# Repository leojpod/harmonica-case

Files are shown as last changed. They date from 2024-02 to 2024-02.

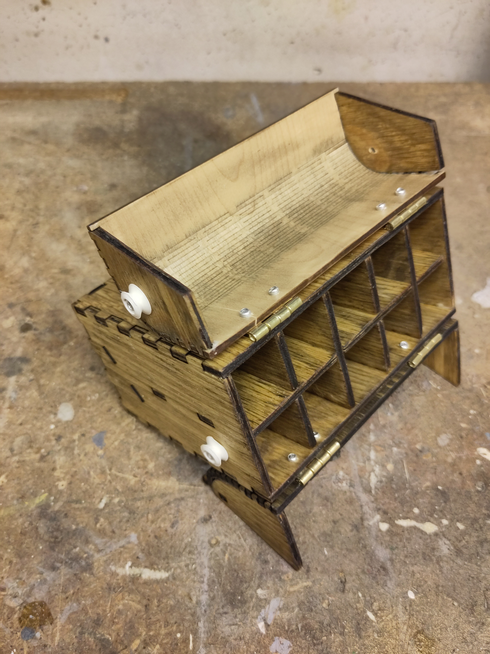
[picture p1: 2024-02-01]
pictures/IMG_20221201_205347.jpg

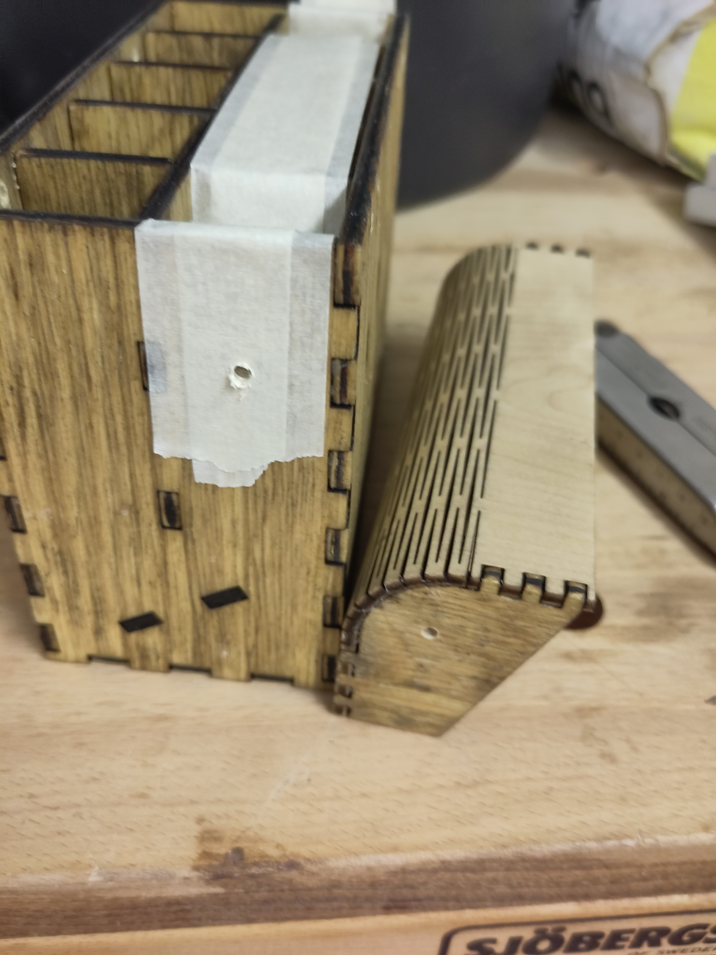
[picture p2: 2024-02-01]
pictures/IMG_20221201_195854.jpg

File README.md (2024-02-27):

# Harmonica carry-case (and show off stand)

## TL;DR

The idea is to create a case that can carry safely about 10 diatonic harmonicas.
The case should also open in a way that would allow to easily locate and pick up the desired harmonica.

## The story behind this

I used to put my harmonicas on my hand made stand-up desk, but I start to have too many to line up like in this picture.



After a few drawing on paper, I thought "why not make something that could hold my harmonicas but also display them".
Few more paper draft later, I started to play with FreeCAD, but I was quite unhappy with it eventually, and I like the ability to "code" my model and to version it.

For specific information about each file, check their "headers".

## How to assemble it?

First, set up the variables in `dimensions.scad`, and make sure they match your harmonicas (or whatever you want to store) and the base material you wish to use.

Then check the `main.scad` file with OpenSCAD, and make sure it looks OK.
Don't hesitate to comment out part of the `BoxOutset` to see inside more easily.

The whole thing is meant to be assembled from laser cut parts.

### 3 by 5 box

#### laser-cut pieces

All the pieces are cut on some 4 mm thick laminated wood.

- For the inset:
  - [ ] 1 horizontal plank
  - [ ] 1 slant plank
  - [ ] 2 even vertical separators
  - [ ] 2 odd vertical separators
- For the outset:
  - [ ] 1 bottom
  - [ ] 2 long side "a"
  - [ ] 2 long side "b"
  - [ ] 2 short side "a"
  - [ ] 2 short side "b"
- For the lid-lock:
  - [ ] 1 example support (optional to check the lock works)
  - [ ] 10 holders
  - [ ] 4 handles
  - [ ] 2 long slider base
  - [ ] 2 short slider base
- For the lid:
  - [ ] the "stand lid part"
    - [ ] 2 stand side
    - [ ] 1 "stand" cover
    - [ ] 1 stabiliser with overhead
  - [ ] the "other lid part"
    - [ ] 2 "other" side
    - [ ] 2 stabilisers without overhead
    - [ ] 1 "other" cover

### Other pieces & material

- the lid lock
  - **_TODO find one and explain it here_**
- the lid hinge joins
  - **_TODO Same_**
- the carry strings
  - **_TODO Same_**

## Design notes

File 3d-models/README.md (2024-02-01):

# 3d Models

Quick summary of the files and what they are used for:

- `dimansions.scad`: regroups different parameters that control the whole thing, mainly, how thick is the material we're working with, how big should be the holds for the harmonicas, how many holds should there be, etc.
- `box-inset.scad`: modelises the horizontal and vertical separators that go inside the box.
- `box-outset.scad`: modelises the outside of the box, this will hold the inset in place and the lid parts are going to attach to it.
- `lid.scad`: contains the 2 parts that are used for the lid.
- `string-lock.scad`: modelises the small things on the side that are used to hold the lid shut.
- `pop-rivet.scad`: was supposed to be used to seal the lid's hinges and the locks on the sides, but in the end I opted for real rivets.

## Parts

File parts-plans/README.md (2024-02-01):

# Part plans

Having a 3D model is fine but that does not give you a part to print/laser cut. So here is where this comes into play.

Depending on your setup, you might want to tweak this files a bit to export only one piece to SVG or some other format at a time.

I will try to find a better way to deal with this.
One idea for that:
https://3dprinting.stackexchange.com/questions/14900/export-stl-from-openscad-command-line-calling-module-within-script

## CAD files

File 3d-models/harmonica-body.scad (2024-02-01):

harmonicaHeight = 30;
harmonicaLength = 105;
harmonicaThickness = 20;

module harmonicaBody() {
    cube([harmonicaLength, harmonicaThickness, harmonicaHeight]);
}

rotate([0,90,0])
  translate([-harmonicaLength,0,0])
  harmonicaBody();

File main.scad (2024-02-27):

// Box body

/*   top
 *   ____
 *  /    \ <- lid
 *  |    |
 *  |    | <- short sides: left & right
 *  |____| <- long sides: front & back
 *   ^ bottom
 *
 *
 *   base: left, right, front, back & bottom (i.e. all but lid)
 */


/*
 * DIMENSIONS
 *
 * Harmonica:
 *  - roughly: 105 x 25 x 30
 *
 * harmonica stored along the X axis
 */
include <./3d-models/dimensions.scad>

use <./3d-models/harmonica-body.scad>

use <./3d-models/box-inset.scad>
use <./3d-models/box-outset.scad>
use <./3d-models/lid.scad>
use <./3d-models/lid-lock.scad>

rotate([0, -($boxTiltingAngle), 0]) {
  translate([$materialThickness,2*$materialThickness,2*$materialThickness]) {
    boxInset();
    // harmonicas as example
    color("white") {
      translate([(2 * $heightGap + $materialThickness) / tan(90-$slantAngle) + $materialThickness, 0, 0])
      for (i=[0:($horizontalPlacements - 1)]) {
        translate([0, i * ($thickGap + $materialThickness), 0])
          harmonicaBody();
      }
      translate([$heightGap/(tan(90-$slantAngle)) + $materialThickness + 2, 0, $heightGap + $materialThickness])
      for (i=[0:($horizontalPlacements - 1)]) {
        translate([0, i * ($thickGap + $materialThickness), 0])
          harmonicaBody();
      }
    }
  }

  boxOutset(extraSpace = 0);
  translate([$boxHeight, 0, 0])
  lid();
  translate([$boxHeight, 0, 0])
    rotate([0, 180, 0])
    standLid();
  translate([$boxHeight, 0, $boxDepth])
    rotate([0, 180, 0])
    translate([0, $boxWidth, 0])
    rotate([180, 0, 0])
    otherLid();

  translate([$boxHeight + $lidHeight*.80, $boxWidth, $boxDepth - 1.5*$lidRadius])
    mirror([0,1,])
    rotate([90, 180, 0])
    slideLock();
  translate([$boxHeight + $lidHeight*.80, 0, $boxDepth - 1.5*$lidRadius])
    rotate([90, 180, 0])
    slideLock();
}

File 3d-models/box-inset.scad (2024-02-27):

include <./dimensions.scad>
use <./harmonica-body.scad>

margin = 5;

insideWidth = $boxWidth - 4* $materialThickness;


function offsetCalculator(level) = 
  $insetMargin + $materialThickness + ($verticalPlacements - level) *($heightGap + $materialThickness) / tan (90-$slantAngle) + 2;


module insideSlant() {
  // inside-slant offset ->
  slantHeight = ($heightGap + ( $heightGap + $materialThickness) * ($verticalPlacements -1)) / sin(90 - $slantAngle) - $materialThickness;
  union() {
    cube([$materialThickness, insideWidth, slantHeight]);
    translate([0, - $materialThickness, (slantHeight / 3) - 5])
    cube([$materialThickness, insideWidth + 2 * $materialThickness, 10]);
    translate([0, - $materialThickness, 2 * (slantHeight / 3) - 5])
    cube([$materialThickness, insideWidth + 2 * $materialThickness, 10]);
  }
}


module horizontalPlank(height, level = 1) {
  echo("horizontalPlank -> ", level);
  offset = offsetCalculator(level);
  offsetted_height = height - offset;
  translate([offset, 0, 0])
  difference () {
    union() {
      //base
      cube([offsetted_height, insideWidth, $materialThickness]);
      // first set of wings
      translate([20, - $materialThickness, 0])
        cube([10, insideWidth + 2 * $materialThickness, $materialThickness]);
      // second set of wings
      translate([offsetted_height - 30, - $materialThickness, 0])
        cube([10, insideWidth + 2 * $materialThickness, $materialThickness]);
    }
    // notches
    for(i=[0:($horizontalPlacements - 2)]) {
      horizontalShift = (i + 1) * $thickGap + (i *  $materialThickness);
      if (i % 2 != 0){
        translate([offsetted_height / 2, horizontalShift, - margin ])
        cube([offsetted_height / 2 + margin, $materialThickness, 2*margin +  $materialThickness]);
      } else {
        translate([- margin, horizontalShift, - margin])
        cube([offsetted_height / 2 + margin, $materialThickness, 2*margin + $materialThickness]);
      }
    }
  }
}

module verticalSeparator(height, is_even = true) {
  offset = offsetCalculator(1);
  offsetted_height = height - offset;
  separator_width = $heightGap + ($verticalPlacements - 1) * ($materialThickness + $heightGap);

  base = 4 + margin + $insetMargin;
  bottomOffset = base + (separator_width + 2 * margin) / tan(90-$slantAngle);

  // wedge cutout
  wedgePoints = [
    [0, 0, separator_width + 2 * margin], // 0
    [base, 0, separator_width + 2 * margin], // 1
    [bottomOffset, 0, 0], // 2
    [0, 0, 0], // 3
    [0, $materialThickness + 2 * margin, separator_width + 2 * margin], // 4
    [base, $materialThickness + 2 * margin, separator_width + 2 * margin], // 5
    [bottomOffset, $materialThickness + 2 * margin, 0], // 6
    [0, $materialThickness + 2 * margin, 0] // 7
  ];
  wedgeFaces = [
    [4, 5, 1, 0], // top
    [0, 1, 2, 3], // front
    [5, 6, 2, 1], // side
    [7, 6, 5, 4], // back
    [6, 7, 3, 2], // bottom
    [7, 4, 0, 3] // other side
  ];

  difference() {
    union() {
      cube([height, $materialThickness, separator_width]);
      translate([2 * height / 3 - 5, 0, - $materialThickness])
        cube([10, $materialThickness, separator_width + 2 * $materialThickness]);
    }
    translate([-margin, -margin, -margin])
      polyhedron(wedgePoints, wedgeFaces);

    for(i=[1:$verticalPlacements - 1]) {
      offset = offsetCalculator(i);
      offsetted_height = height - offset;
      if (is_even) {
        translate([offset + offsetted_height / 2, -margin, $heightGap + ($heightGap + $materialThickness) * (i-1)])
          cube([offsetted_height / 2 + margin, $materialThickness + 2 * margin, $materialThickness]);
      } else {
        translate([offset - margin, -margin, $heightGap + ($heightGap + $materialThickness) * (i-1)])
          cube([offsetted_height / 2 + margin, $materialThickness + 2 * margin, $materialThickness]);
      }
    }
  }
}

module boxInset(height = $insetLength, isSplit = false) {
  for(i=[1:($verticalPlacements - 1)]) {
    translate([0, 0, $heightGap + (i-1) * ($heightGap + $materialThickness)])
      horizontalPlank(height, i);
  }

  translate([(isSplit? -1.2*height : 0) + offsetCalculator(0) - $materialThickness * 2, 0, 0.25 * $materialThickness])
  rotate([0, -$slantAngle, 0])
    insideSlant();

  for(i=[0:($horizontalPlacements - 2)]) {
    x_offset = isSplit ? ((i % 2 == 0) ? -1.1*height : 1.1*height) : 0;
    horizontalShift = [x_offset, (i + 1) * $thickGap + i * $materialThickness, 0];
    if(i % 2 == 0) {
      color("blue")
      translate(horizontalShift)
      verticalSeparator(height, true);
    } else {
      color("green")
      translate(horizontalShift)
      verticalSeparator(height, false);
    }
  }
}

boxInset(isSplit = false);

if (false) {
  translate([offsetCalculator(0), 0, 0])
    union() {
      color("white")
      harmonicaBody();
      color("magenta")
      cube([$minHarpSeating, 20, 30]);
    }
  color("teal")
  translate([offsetCalculator(1), 0, $materialThickness + $heightGap])
    harmonicaBody();
  translate([offsetCalculator(2), 0, 2*$materialThickness + 2*$heightGap])
    union() {
      color("gray")
      harmonicaBody();
      color("blue")
      cube([$maxHarpSeating, 20, 30]);
    }
}

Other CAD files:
3d-models/box-outset.scad
3d-models/dimensions.scad
3d-models/fabric-holder.scad
3d-models/lid-lock.scad
3d-models/lid.scad
3d-models/pop-rivet.scad
3d-models/string-lock.scad
3d-models/utils/crenel.scad
3d-models/utils/cylinder-outer.scad
parts-plans/all-layouts.scad
parts-plans/box-inset-plans.scad
parts-plans/box-outset-plans.scad
parts-plans/lid-lock-plans.scad
parts-plans/lid-plans.scad

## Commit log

2022-11-14 let's start with openSCAD at least I'll have versioning...
    [box-inset.scad, dimensions.scad, harmonica-body.scad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]
2022-11-14 inset completed
    [box-inset.scad, main.scad]
2022-11-14 more stuff, almost there
    [box-inset-plans.scad, box-inset.scad, box-outset-plans.scad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]
2022-11-14 that should do it for the first version
    [lid-plans.scad, lid.scad]
2022-11-14 starting to adjust after the draft version has been assembled
    [all-layouts.scad, box-inset-plans.scad, box-inset.scad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]
2022-11-20 more adjusmtents, only the cork lead thickness to adjust now
    [box-outset.scad, dimensions.scad, lid-plans.scad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]
2022-11-20 small adjusmtents, used for wood and cork version.
    [box-inset-plans.scad, box-outset.scad, lid-plans.scad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]
2022-11-24 update for the wooden version of the lid
    [crenel.scad, lid-plans.scad, lid.scad]
2022-11-25 woops, the rounded pieces were too big...
    [lid.scad]
2022-12-01 add the cylinder-outer to make sure the holes are correctly sized add the model for the pop-rivet (unused in the end) add the model for the string-lock (locked with the broken tube from my bike inste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
    [cylinder-outer.scad, pop-rivet.scad, string-lock.scad]
2024-02-01 shuffling things around and fixing the inset and outset, now onto the lid
    [all-layouts.scad, box-inset-plans.scad, box-inset.scad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]
2024-02-01 more stuff
    [box-inset.scad, box-outset.scad, lid.scad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]
2024-02-16 more smallish steps
    [box-inset-plans.scad, box-inset.scad, box-outset-plans.scad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]
2024-02-19 that should almost be a working lid
    [lid.scad]
2024-02-20 that might work
    [crenel.scad, dimensions.scad, lid-lock.scad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]
2024-02-26 introducing the double layer sides
    [box-outset.scad, crenel.scad, dimensions.scad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]
2024-02-27 parts-plans/pieces === dist/
    [box-inset-plans.scad, box-inset.scad, box-outset-plans.scad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]
2024-02-28 tiny changes, many files
    [box-inset-plans.scad, box-outset-plans.scad, box-outset.scad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]
2024-03-24 add a new piece to hopefully help with holding the fabric in place without all the hassle of glueing it...
    [fabric-holder.scad]
